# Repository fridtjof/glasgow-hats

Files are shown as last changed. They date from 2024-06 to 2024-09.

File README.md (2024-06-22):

# some HATs for the glasgow

okay there's just one so far but i've got another one i just haven't
put together yet. it's pretty simple, too.

## kicad library

in the 'kicadlib' directory, and the Releases area of github, there's
a downloadable library you can install into kicad which includes two
symbols and a footprint for making glasgow HATs. see the README in that
directory for more details.

## super breakout screw terminal hat

the name could use some work. brings the pins multiple ways, ending
in screw terminals with some holes through the PCB for optional
strain relief.

this was created when i was working on interfacing with something
through a cable i'd cut in half. i needed to bring the individual
wires into screw terminals, ideally keeping them from pulling out.
i also had to put a logic analyzer and a scope on some of the lines
to figure out what was going on. this would've been really handy.

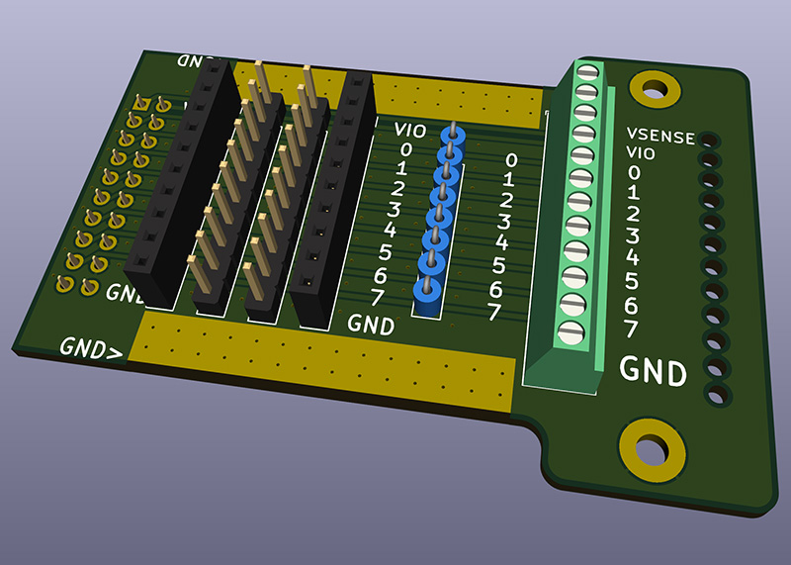
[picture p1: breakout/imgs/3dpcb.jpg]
3D view of the PCB with parts


# related content

- [my glasgow fork](https://github.com/jkominek/glasgow) has the various
  applets i've written, in it.
- [x16glasgow](https://github.com/jkominek/x16glasgow) is a HAT which adapts
  the glasgow to the Commander X16's bus as an MMIO device.

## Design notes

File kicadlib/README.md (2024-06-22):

# kicad library for glasgow hats

i was tired of double checking that my connector was flipping around
correctly.

everything is laid out so that the connectors should be soldered in
on the side that the 3D view things they're on. for the single port
that'll default to being on top of the board. for the double port
that'll default to being on the bottom of the board. (obviously flipping
the footprint will reverse that.) in large part that was so that
the single port could use the default connector footprint.

the outline present in User.Drawings for the dual port footprint
corresponds to the aluminum case from 1bitsquared.

feel free to open issues or PRs for suggestions/improvements.

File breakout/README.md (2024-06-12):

# features

Okay, per the picture:

3D view of the PCB with parts

you can work out most things.

The four rows of 0.100" header pins are intended to go female, male,
male, female, to minimize the opportunity for shorts with the female
header that the board uses to plug into the glasgow.

Speaking of which, if you used a header with very long pins for that,
you could plug the breakout cable that comes with the 1BitSquared
Glasgow into those pins, and use it, too.

The 8-pin connector is intended for looped test points, so that you
can clip oscilloscope probes on to the lines. The exposed planes along
the edges are for your probe's ground clip.

On the right there's space for screw terminals. Ground is
available twice, just in case there are two grounds in the cable
(or whatever) that you're working with, and you'd like to secure
both of them.

Finally, the little holes are for optional strain relief. You can run
your wires through them before tightening them down in the screw
terminals. Should reduce the likelihood that they'll pop out at an
awkward moment.

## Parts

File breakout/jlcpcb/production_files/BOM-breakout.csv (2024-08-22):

Comment | Designator | Footprint | LCSC
FX2LA | J9 | PinSocket_2x05_P2.54mm_Vertical
SignalsMale | J5 | PinHeader_1x10_P2.54mm_Vertical
SignalsFemale | J4 | PinSocket_1x10_P2.54mm_Vertical
SignalsMale | J3 | PinHeader_1x10_P2.54mm_Vertical
TestPoints | J7 | PinHeader_1x08_P2.54mm_Vertical
ScrewTerminals | J2 | TerminalBlock_not_WAGO_233-512_2x12_P2.54mm
SignalsFemale | J6 | PinSocket_1x10_P2.54mm_Vertical
Glasgow | J1 | PinSocket_2x10_P2.54mm_Vertical

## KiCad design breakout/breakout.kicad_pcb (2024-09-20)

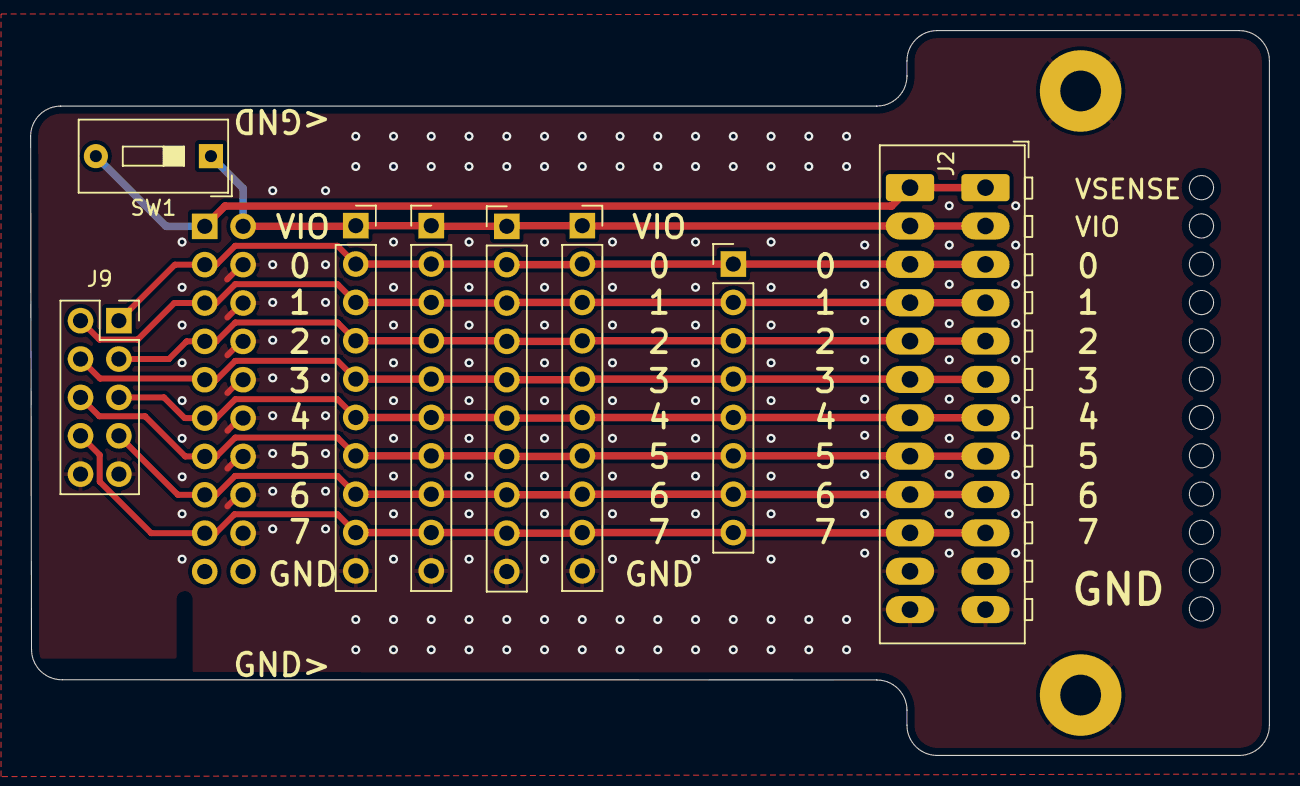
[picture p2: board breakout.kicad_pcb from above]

Board: 2 copper layers, 82.0 x 48.0 mm, 11 parts (1 on the bottom side), 11 nets.

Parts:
H1, H2: MountingHole_Pad; MountingHole_2.7mm_M2.5_Pad
J1: Glasgow; PinSocket_2x10_P2.54mm_Vertical
J2: ScrewTerminals; TerminalBlock_not_WAGO_233-512_2x12_P2.54mm
J3, J5: SignalsMale; PinHeader_1x10_P2.54mm_Vertical
J4, J6: SignalsFemale; PinSocket_1x10_P2.54mm_Vertical
J7: TestPoints; PinHeader_1x08_P2.54mm_Vertical
J9: FX2LA; PinSocket_2x05_P2.54mm_Vertical
SW1: SW_SPST; SW_DIP_SPSTx01_Slide_9.78x4.72mm_W7.62mm_P2.54mm

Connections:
/D0: J1.3, J2.3, J3.2, J4.2, J5.2, J6.2, J7.1, J9.1
/D1: J1.5, J2.4, J3.3, J4.3, J5.3, J6.3, J7.2, J9.2
/D2: J1.7, J2.5, J3.4, J4.4, J5.4, J6.4, J7.3, J9.3
/D3: J1.9, J2.6, J3.5, J4.5, J5.5, J6.5, J7.4, J9.4
/D4: J1.11, J2.7, J3.6, J4.6, J5.6, J6.6, J7.5, J9.5
/D5: J1.13, J2.8, J3.7, J4.7, J5.7, J6.7, J7.6, J9.6
/D6: J1.15, J2.9, J3.8, J4.8, J5.8, J6.8, J7.7, J9.7
/D7: J1.17, J2.10, J3.9, J4.9, J5.9, J6.9, J7.8, J9.8
/VSENSE: J1.1, J2.1, SW1.2 (B)
GND: H1.1, H2.1, J1.4, J1.6, J1.8, J1.10, J1.12, J1.14, J1.16, J1.18, J2.11, J2.12, J3.10, J4.10, J5.10, J6.10, J9.9, J9.10
VBUS: J1.2, J2.2, J3.1, J4.1, J5.1, J6.1, SW1.1 (A)

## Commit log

2024-06-12 first HAT
    [breakout.kicad_pcb, breakout.kicad_sch]
2024-06-12 how to use a completely passive device
2024-06-22 kicad library for making hats
2024-07-29 [wip] add connector for generic fx2 logic analyzers
    [breakout.kicad_pcb, breakout.kicad_sch]
2024-08-22 get jlc'd
    [CPL-breakout.csv, breakout-CuBottom.gbr, breakout-CuTop.gbr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]
2024-09-20 wip? rev2
    - rounded corners
    - more LA space (todo confirm spacing re: glasgow center)
    - vio/vsense connection switch
    [breakout.kicad_pcb, breakout.kicad_sch]
